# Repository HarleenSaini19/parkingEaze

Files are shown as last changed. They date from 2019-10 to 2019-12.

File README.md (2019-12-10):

# Ek1254 -IR Infrared Sensor

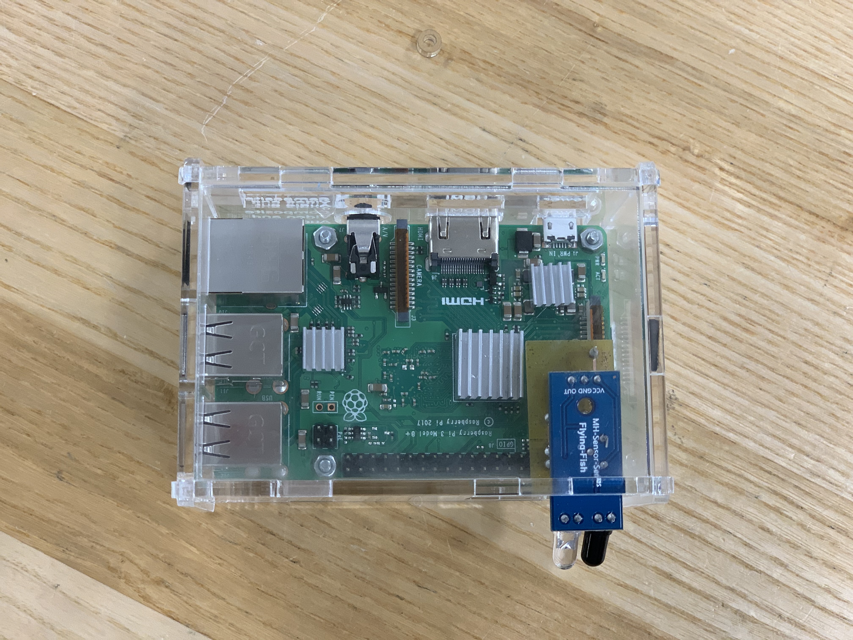
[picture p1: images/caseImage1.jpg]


### Purpose
- The purpose of this project is to reduce parking problems using Ek1254 sensor. Ek1245 infrared sensor will detect if there is any car parked in the parking spot.

## Table of Contents
1. [Introduction](#introduction)
2. [System Diagram](#system-Diagram)
3. [Materials](#materials)
4. [Budget](#budget)
5. [Time Commitment](#time-Commitment)
6. [Setting up Raspberry Pi](#setting-Up-Raspberry-Pi)
7. [Hardware Testing](#hardware-Testing)
8. [Mechanical Assembly](#mechanical-Assembly)
9. [PCB Soldering](#pcb-Soldering)
10. [Power Up](#power-up)
11. [Unit Testing](#unit-Testing)
12. [Production Testing](#production-Testing)
13. [Conclusion](#conclusion)

## Introduction
- IR Infrared Sensor can be widely used in obstacle avoidance car, line count, and black and white line tracking and so on.
- The module detects the distance 2 ~ 30cm, detection angle 35 °, the distance can detect potential is adjusted.
- The output port OUT sensor module can be directly connected to the microcontroller IO port, you can directly drive a 5V relay.
- It has a pair of infrared transmitting and receiving tube, tube infrared emit a certain frequency, when detecting direction meet with obstacles (reflecting surface), reflected infrared receiving tube, after the comparator circuit processing, green indicator will light up, at the same time signal output interface to output digital signal (a low level signal).
- Can be used for 3-5V DC power supply modules. It has red power indicator.

## System Diagram 

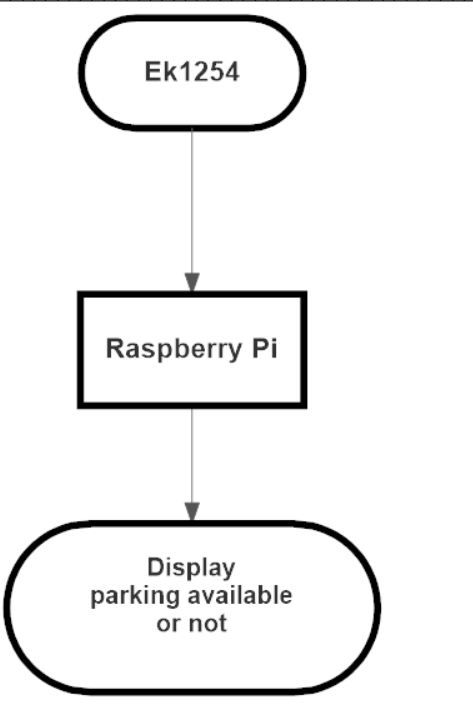
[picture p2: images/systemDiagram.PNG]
systemdiagram


## Materials
- [Raspberry Pi](https://www.amazon.ca/CanaKit-Raspberry-Starter-Premium-Black/dp/B07BD56DW5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) 
- [Ek1245](https://www.amazon.ca/gp/product/B07FFM7DYQ/ref=ppx_yo_dt_b_asin_title_o06_s00?ie=UTF8&psc=1) -IR Infrared Sensor
- Breadboard and [jumper wires](https://www.amazon.ca/dp/B01M1IEUAF/ref=dp_cerb_1) for initial testing
- [Socket Header](https://www.amazon.ca/gp/product/B07CWSXY7P/ref=ppx_yo_dt_b_asin_title_o00_s00?ie=UTF8&psc=1) to attach sensor and pi together on [PCB](https://raw.githubusercontent.com/HarleenSaini19/parkingEaze/master/images/pcb_frontSide.jpg).For production export it to the gerber files. 
- Case to hold ciruit together and prevent it from damage.Here is design of my [case](https://github.com/HarleenSaini19/parkingEaze/blob/master/mechanical/HKSPi3Case%20New.cdr).You can also check acrylic cases [here](https://www.thingiverse.com/search?q=raspberry+pi+3+laser&dwh=445defe2659844c).
 - [Note]: These things might take time to deliver so make sure you order everything before.

## Budget
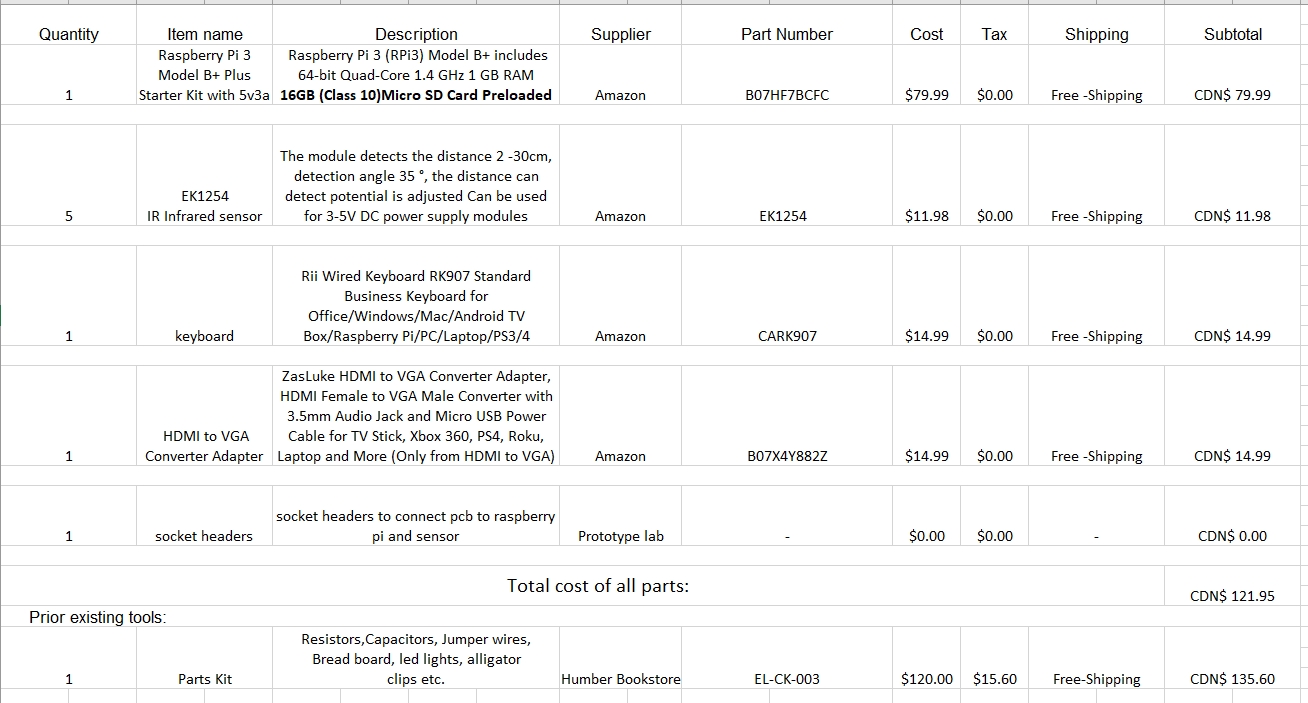
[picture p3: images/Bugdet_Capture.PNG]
capture


## Time Commitment
This project can be done in a week if one gives 2-3 hours a day. It will take about 2 to 4 days to recieve the parts. If you want to skip breadboarding then you can get started with the soldering which would take about 10 minutes but testing can take about 3-4 hours. After soldering is tested, it should take about 1-2 hours to power up the PCB and run the python script and get the readings.

## Setting up Raspberry Pi
First step after getting your raspberry pi is to set it up. Follow the steps below:
1. Download [Raspbian](https://www.raspberrypi.org/downloads/) to be installed on your raspberry pi.
2. Use [SDCardFormatter](https://www.sdcard.org/downloads/formatter_4/) to format your SD card and flash downloaded OS on your SD card.
3. Insert SD card in raspberry pi and connect the side devices like keyboard and mouse.
4. Switch on the power and finish the further setup.

## Hardware Testing

After software installation, i made the connections using jumper wires from sensor to breadboard and breadboard to raspberry pi.

Wiring:
---
- Raspberry Pi 3V  to sensor VCC
- Raspberry Pi GND to sensor GND
- Raspberry Pi GPIO4 to sensor OUT

Since there is no SCL and SDA pin.Therefore, there will be no i2c bus address

### Raspberry Pins
This wiring diagram could be helpful to make the connections on breadboard
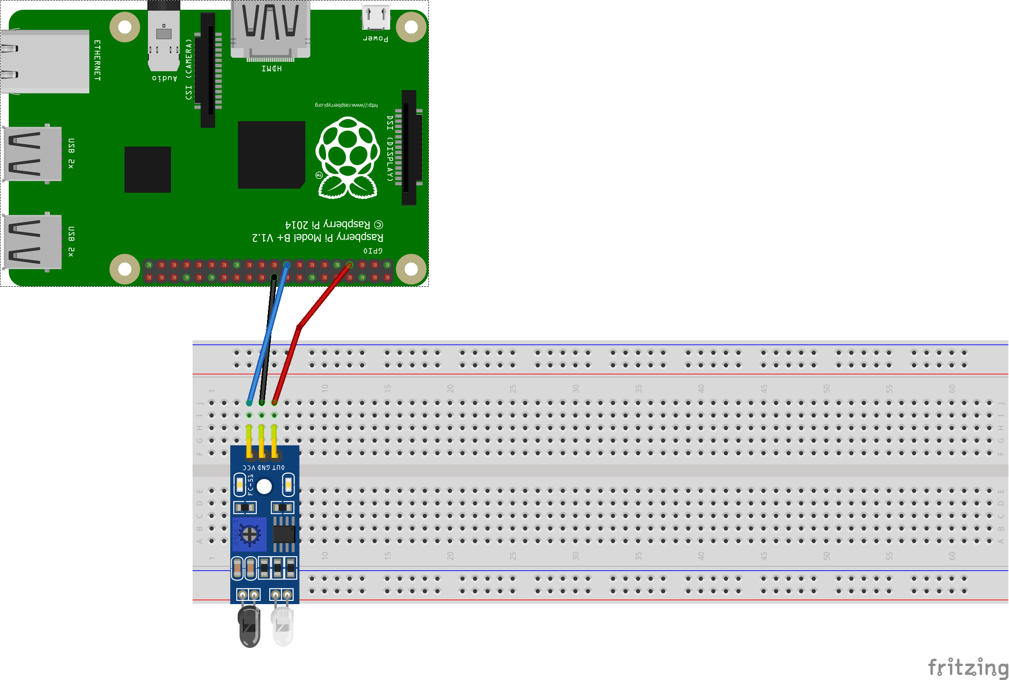
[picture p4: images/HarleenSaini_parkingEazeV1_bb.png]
fritz_bb


## Mechanical Assembly
Either you can connect you pi to your sensor using breadboard connections or you can solder your sensor.
Breadboarding is just to check if sensor works as expected or their is a need to change some connections or if there is a damaged component.

| EK1254| Raspberry Pi |
| ----- | ----- |
|  VIN  |  3V |
|  GND  |  GND 	|
|  OUT 	|  GPIO4|

## PCB
Here is my PCB Design:
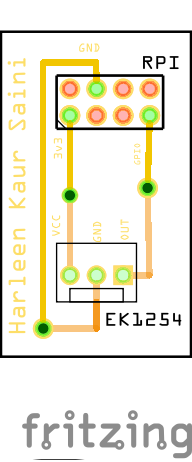
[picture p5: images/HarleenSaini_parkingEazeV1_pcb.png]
fritz_pcb


After soldering my pcb, it looks like this:
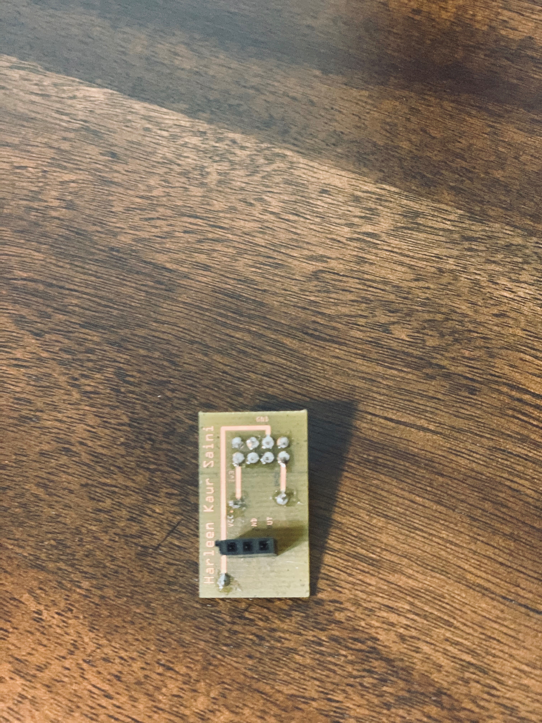
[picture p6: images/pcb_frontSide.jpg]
pcb

there are socket headers to connect raspberry pi and sensor to the pcb.

## Power Up
After all the components are connected, your PCB should look like this.
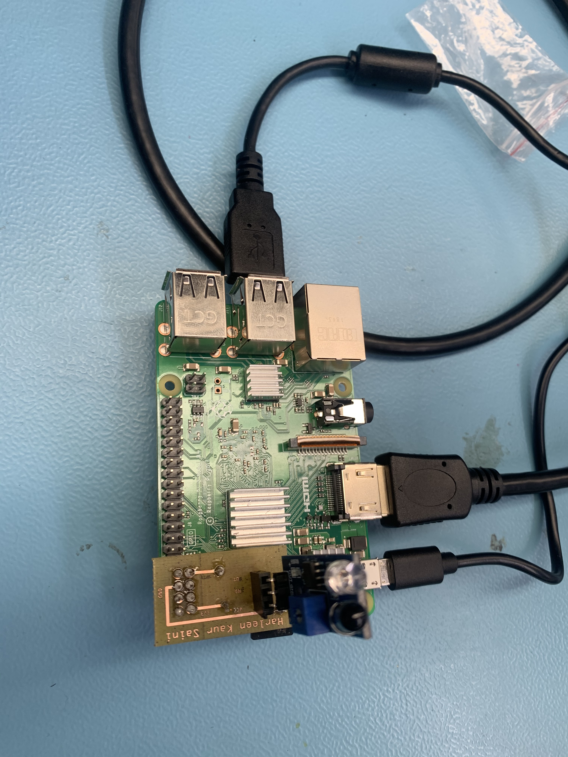
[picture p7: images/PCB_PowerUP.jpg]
PCB_PowerUP
 

## Unit Testing

### Python Script
You can use the code underneath to get the readings from your sensor:
```
import RPi.GPIO as GPIO
from time import sleep

GPIO.setmode(GPIO.BCM)
GPIO.setup(4,GPIO.IN)

while True:
    sensor = GPIO.input(4)
    if sensor ==1:
        print("Parking Slot Available")
        sleep(1)

    elif sensor ==0:
        print("Parking Slot filled")
		sleep(1)
```

### Final Testing
Running python script will get you the readings
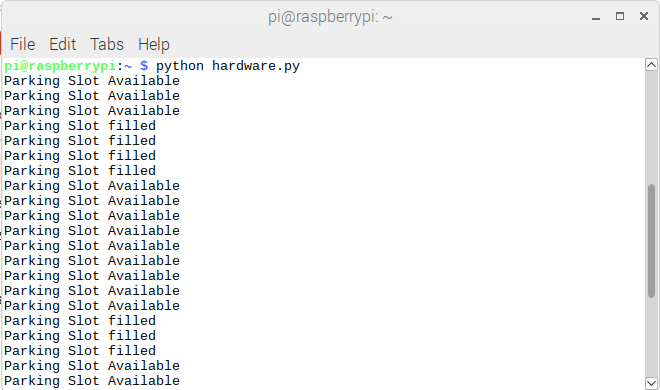
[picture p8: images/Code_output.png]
reading


### Enclosure
If your raspberry pi is working with the sensor and you are getting  readings then you can go further and make your acrylic case to prevent your raspberry pi and sensor from getting damaged.

If you are successful in making your case, it should look like this.
design1
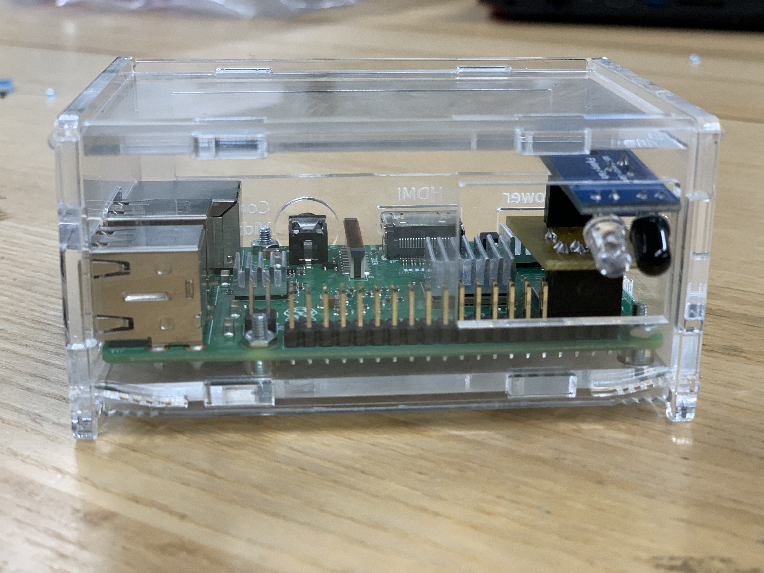
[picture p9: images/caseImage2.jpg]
design2

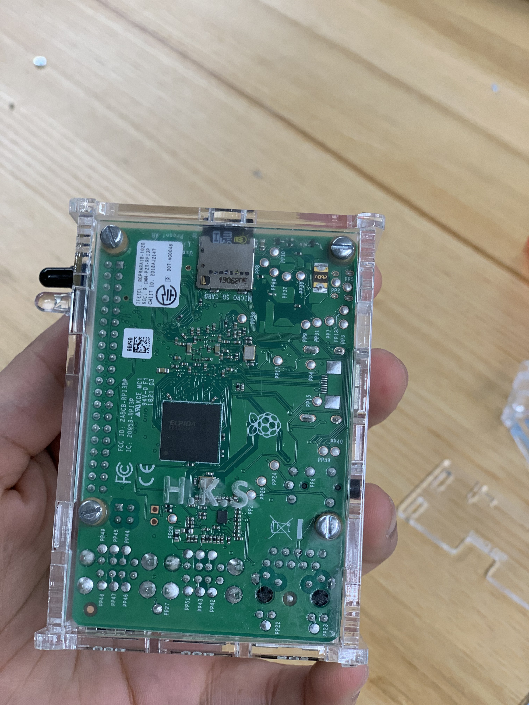
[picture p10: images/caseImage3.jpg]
design3

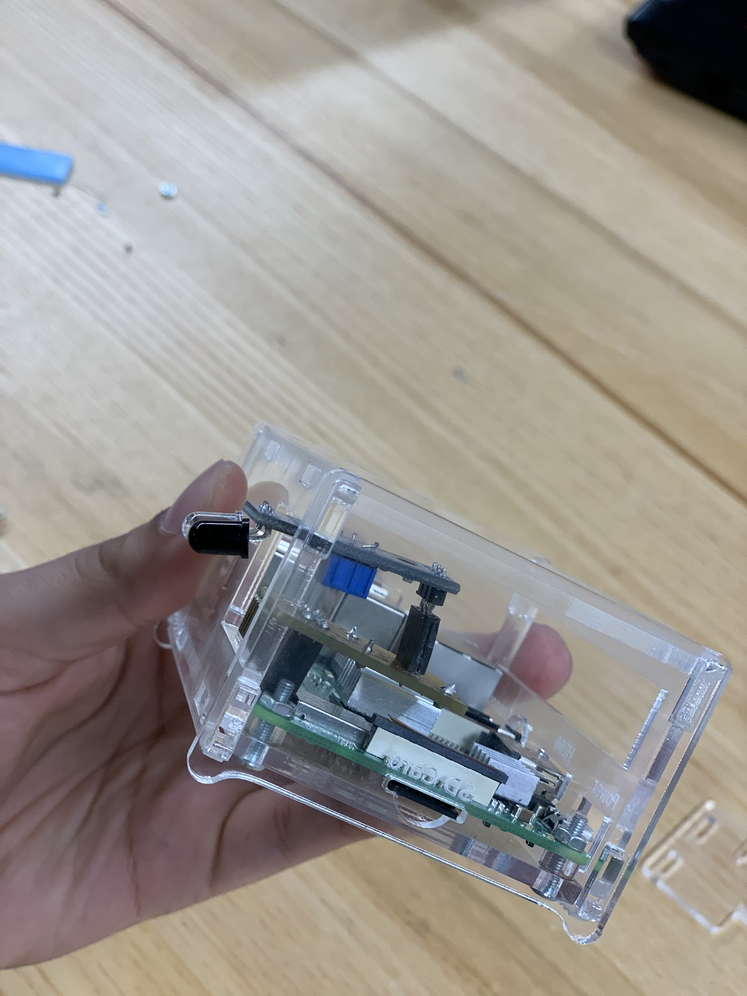
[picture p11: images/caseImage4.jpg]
design4


## Production Testing
For mass production of this sensor, there are very rare chances of any drawbacks.The PCBs will be mass soldered and will be tested for connectivity at the end of the production line using a simple resistance test.For mass production testing it can be easily tested as when you will connect your sensor to raspberry pi without running the code you can see if there is any object which is in the range of the sensor the led of the sensor will glow this will tells you that you have done your soldering accurately.

## Conclusion
The project is easily reproducible by following the instructions. The project can be done using an Arduino, which costs less than the Raspberry Pi, however the steps that will be taken to create this project will be way different than the instructions explained above.

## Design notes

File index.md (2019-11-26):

<html> 
    	<h1><center>Parking Eaze Project</center></h1>
      	<h2><center>Parking IOT system scale model 2019-2020</center></h2>
  <body>
   <h3><u>Nov 26 2019(Blog #12)</u></h3>
   <h2>Presentation</h2>
   <p> <a href="documentation/Parking_system_ IOT_Scale_model(EK1254-IR).pptm"> Click here</a> to get the presentation file.</p>
   <h3><u>Nov 19 2019(Blog #11)</u></h3>
   <h2>Enclosure</h2>
   <h4>Case Design</h4>
   <p>Case image1</p>
   <p>Case image2</p>
   <p>Case image3</p>
   <p>Case image</p>
   <h2>Design File</h2>
   <p> <a href="mechanical/HKSPi3Case New.cdr"> Click here</a> to get the CorelDRAW design files used for the case design.</p>
   <h3><u>Nov 12 2019(Blog #10)</u></h3>
   <h4><b>Progress Report</b></h4>
<p><b>During the soldering first I soldered the header on the opposite side of the PCB,I didn't knew this until I mounted the pcb on raspberry pi.Therefore, I resoldered it in its correct position.Secondly, while running the code in python when I compiled it dosen't showed any error but my code was not working properly. Then my instructor give me suggestion to check the Raspberry Pi GPIO pinout. Then I figured out that I was using wrong GPIO pin. Other then these two things rest everything was working smoothly for me.</b></p>
   <h4><b>PCB Power Up</b></h4>
   <p>PCB Power Up</p>
   <h3><u>Nov 5 2019(Blog #9)</u></h3>
   <p><b>Down below is my soldered PCB that has been tested and is working fine. My project is on schedule but there is some changes in my bugdet the headers which i didn't mentioned in my
   bugdet luckily i got from the next door i.e the prototype lab. To give more time to my  project i started working from home so i needed one monitor , keyboard, mouse and one HDMI to VGA
   Converter. By chance i was having mouse and a monitor at home so there was no need to buy them. Therefore, i bought HDMI to VGA converter and a keyboard. Here is the  <a href=" https://raw.githubusercontent.com/HarleenSaini19/parkingEaze/master/images/proof_of_purchase_keyboard_%26_converter.PNG"> proof of purchase </a>
   of both the items.
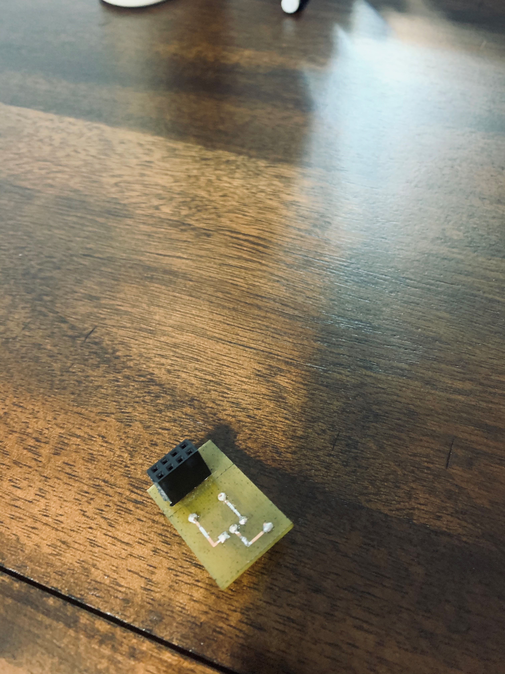
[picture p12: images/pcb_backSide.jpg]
    
    <p>pcb soldering</p>
	<h3><u>Oct 29th 2019(Blog #8)</u></h3>
	<h2>Breadboard</h2>
	<p><b>After software installation, I made the connections using jumper wires from sensor to breadboard and breadboard to raspberry pi</b></p>
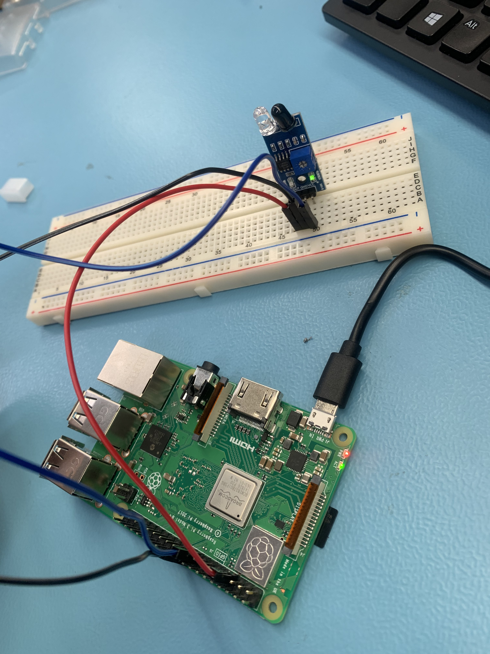
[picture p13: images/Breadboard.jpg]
Breadboard Milestone
	
	<p><b>When their is any obstacle</b></p>
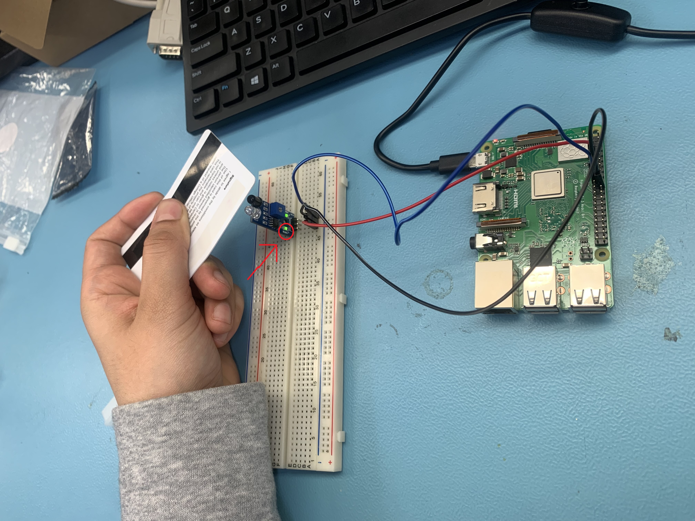
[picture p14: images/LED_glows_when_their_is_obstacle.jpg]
When their is obstacle
	
	<p><b>When their is no obstacle</b></p>
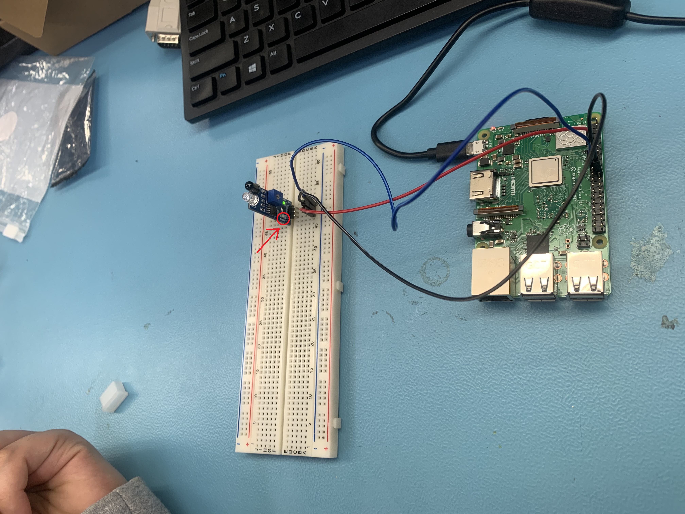
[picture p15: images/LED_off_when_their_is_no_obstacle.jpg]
When their is no obstacle
	
	<p><b>Output Of my code</b></p>
	<p>Code Output</p>
	<p><b>Code in Python</b></p>
	<p><a href = "https://github.com/HarleenSaini19/parkingEaze/blob/master/firmware/hardware.py">Code</a></p>
    <h3><u>Oct 15th 2019(Blog #6)</u></h3>
	<p><b>PCB</b></p>
    <p>PCB</p>
	<p><b>Schematic</b></p>
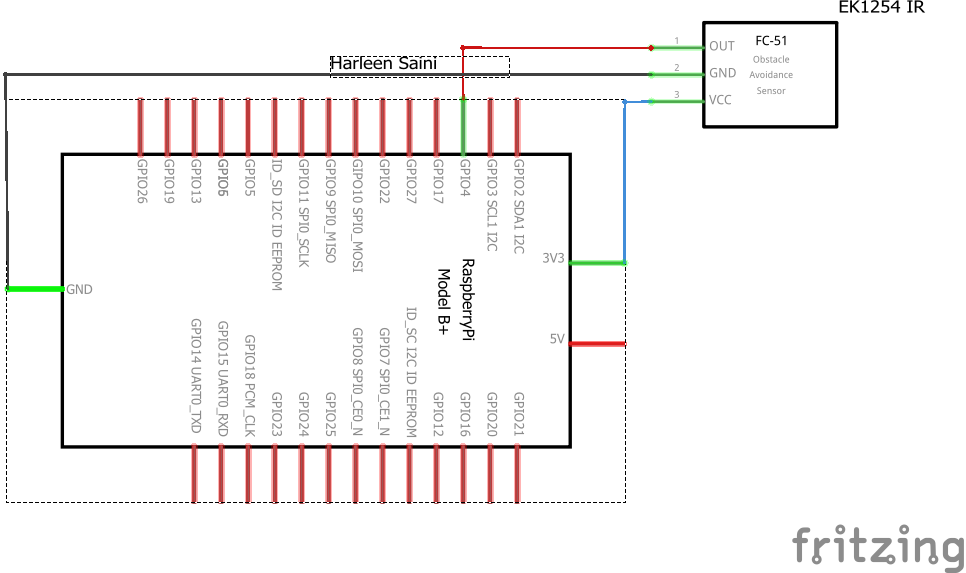
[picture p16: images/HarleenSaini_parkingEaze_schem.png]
Schematic
    
	<p><b>Breadboard</b></p>
    <p>Breadboard</p>
	<h3><u>Oct 1st 2019 (Blog #5)</u></h3>
	<p><b>Proof of Purchase</b></p>
	<p> Proof of Purchase</p>
	<h3><u>Sept 24th 2019 (Blog #4)</u></h3>
	<p> <a href="https://github.com/HarleenSaini19/parkingEaze/blob/master/documentation/budget.xlsx">Bugdet</a></p>
	<h3><u>Sept 17th 2019 (Blog #3 )</u></h3>
	<p> <a href="https://github.com/HarleenSaini19/parkingEaze/blob/master/documentation/Schedule.mpp">Schedule</a></p>
	<h3><u>Sept 10th 2019 (Blog #2 )</u></h3>
	<p> <a href="https://github.com/HarleenSaini19/parkingEaze/blob/master/documentation/ProposalContentHarlenKaurSainiRev03.xlsx">Proposal</a></p>
	<h3><u>Sept 3rd 2019 (Blog #1)</u></h3>
	<p>Repository is created</p>

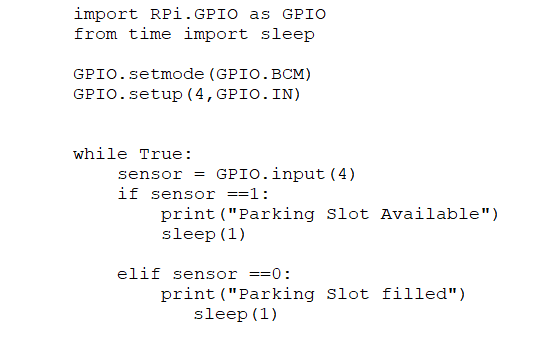
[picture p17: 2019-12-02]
images/python_script_capture.PNG

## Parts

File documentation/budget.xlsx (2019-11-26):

Harleen Kaur Saini
Quantity | Item name | Description | Supplier | Part Number | Cost | Tax | Shipping | Subtotal
1 | Raspberry Pi 3 Model B+ Plus Starter Kit with 5v3a Charger | Raspberry Pi 3 (RPi3) Model B+ includes 64-bit Quad-Core 1.4 GHz 1 GB RAM 16GB (Class 10)Micro SD Card Preloaded with NOOB v2.8+ | Amazon | B07HF7BCFC | $79.99 | $0.00 | Free -Shipping | CDN$ 79.99
5 | EK1254 IR Infrared sensor | The module detects the distance 2 -30cm, detection angle 35 °, the distance can detect potential is adjusted Can be used for 3-5V DC power supply modules | Amazon | EK1254 | $11.98 | $0.00 | Free -Shipping | CDN$ 11.98
1 | keyboard | Rii Wired Keyboard RK907 Standard Business Keyboard for Office/Windows/Mac/Android TV Box/Raspberry Pi/PC/Laptop/PS3/4 | Amazon | CARK907 | $14.99 | $0.00 | Free -Shipping | CDN$ 14.99
1 | HDMI to VGA Converter Adapter | ZasLuke HDMI to VGA Converter Adapter, HDMI Female to VGA Male Converter with 3.5mm Audio Jack and Micro USB Power Cable for TV Stick, Xbox 360, PS4, Roku, Laptop and More (Only from HDMI to VGA) | Amazon | B07X4Y882Z | $14.99 | $0.00 | Free -Shipping | CDN$ 14.99
1 | socket headers | socket headers to connect pcb to raspberry pi and sensor | Prototype lab | - | $0.00 | $0.00 | - | CDN$ 0.00
Total cost of all parts: |  |  |  |  |  |  |  | CDN$ 121.95
Prior existing tools:
1 | Parts Kit | Resistors,Capacitors, Jumper wires, Bread board, led lights, alligator clips etc. | Humber Bookstore | EL-CK-003 | $120.00 | $15.60 | Free-Shipping | CDN$ 135.60

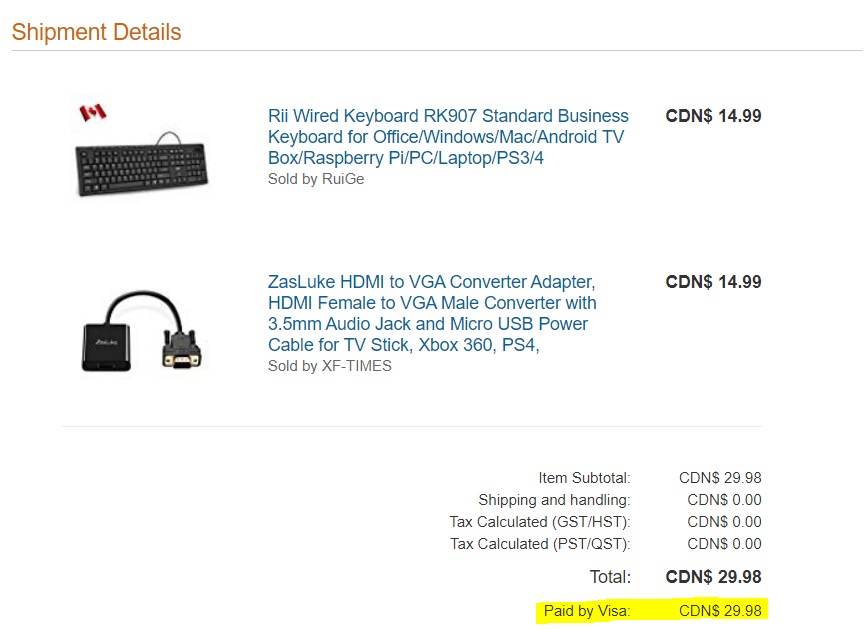
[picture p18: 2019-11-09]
images/proof_of_purchase_keyboard_&_converter.PNG

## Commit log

2019-11-25 update budget
    [budget.xlsx]
2019-11-26 buget updated
    [budget.xlsx]
